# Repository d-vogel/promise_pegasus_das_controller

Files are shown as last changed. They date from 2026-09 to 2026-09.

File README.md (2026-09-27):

# Promise Pegasus DAS controller

The Promise Pegasus DAS is a thuderbolt 2 DAS enclosure.
| Front | Back |
|:-:|:-:|
|front|back|

The goal here is to reverse engineer the backplane and replace the RAID controller with a SATA breakout board and microcontroller.

# Current Status
## reverse engineering
The reverse engineering of the backplane is done, for now described in [docs/backplane.md](docs/backplane.md).

## v0
The first PCB version is not present on the repo. The pinout for both the PCI connector and the ATX24 connector was completely wrong.
Is seems in the debugging process I damaged the CPLD controlling the LEDs, which is why v2 will add a ws2812 control pin.

## v1
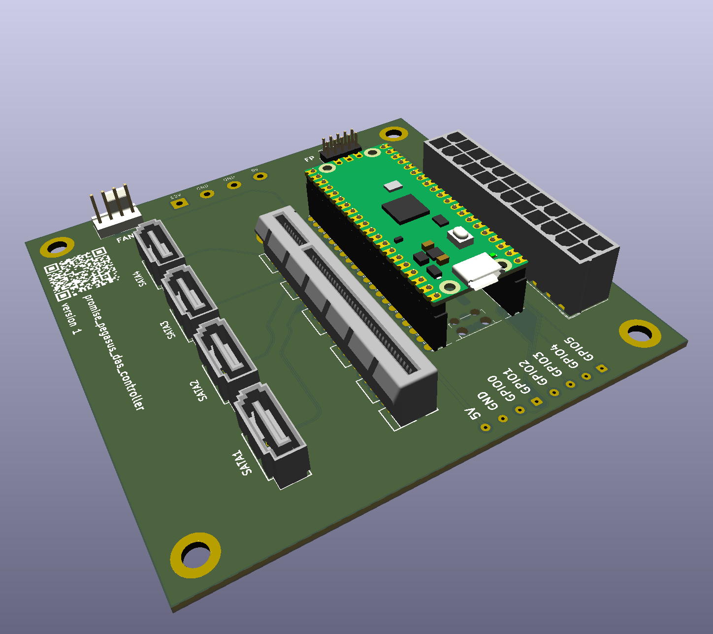
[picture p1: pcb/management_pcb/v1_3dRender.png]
v1


This is the current version on the PCB. Pinouts are correct: 
- ✅ the pico is always on
- ✅ the front panel interfaces to the pico
- ✅ pico triggers the PSU
- ✅ CPLD control pins arrive where they should
- ✅ Disk power enable pins work
- ✅ sata works (tested with HDD1 only)
- ❌ ground fill missing, bodge wires were needed.

## v2 (TODO)
- add ws2812 control pin to pico
- add ground fill to the PCB
- add onboard temperature sensor

## v3 eInk front panel?
[waveshare 2.9 inch E-paper Module](https://www.waveshare.com/2.9inch-e-paper-module.htm)

# BOM:
- SATA: https://www.mouser.ch/ProductDetail/Adam-Tech/SATA-A-PL-VT-K-1
- PCI: https://www.mouser.ch/ProductDetail/Amphenol-FCI/10018783-10212TLF
- ATX24pin: https://www.mouser.fr/ProductDetail/TE-Connectivity/1-1775099-3?qs=28ld6GkVMjRzvehyCXdQkg%3D%3D

pio simulator: https://ice458.github.io/tools/pio_sim/index.html

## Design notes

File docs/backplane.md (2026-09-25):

# Backplate
## Hardware

The backplane is connected to the controller by it's edge into a PCIe x8 connector.

| [Front](backplane_pinout-front.png) | [Back](backplane_pinout-back.png) |
|-|- |
| front | back |

Its' fonctionalities:
- route 12V and 5V to the disks
- pairs of disks can be powered on/off using `ENABLE_HDD12` and `ENABLE_HDD34` pins

- each disk has a blue activity led and a RGB (orange+blue+red) status led so that's 16 leds in total. These are controlled by the CPLD on the backplane. 
- The CPLD is controlled with a special seral protocol on `LED_CLK`, `LED_DATA`, `LED_LATCH_0` and `LED_LATCH_1` pins.
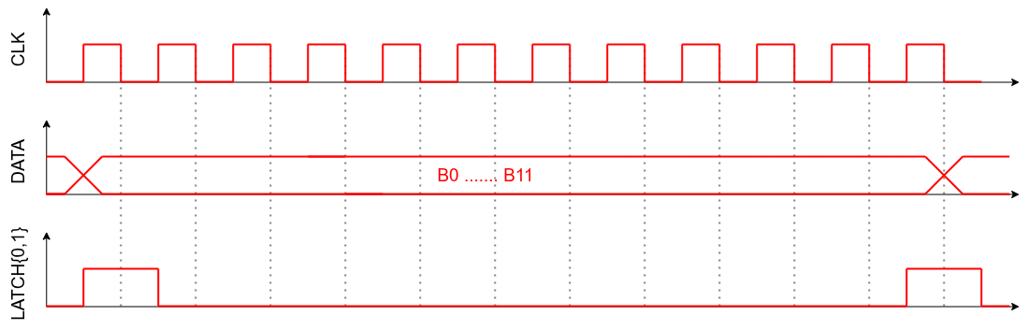
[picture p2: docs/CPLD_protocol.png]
led_protocol
- The procol is based on 12bit frames send over the DATA line at 62.5kHz. Latch signals are set high between each frame: 
- Bits are goupped by 3 for each of the 4 drive slots. The MSB of the group is the blue activity led, and the 2 LSBs are for the status led:
    |b2|b1|b0|result|
    |-|-|-|-|
    |0|x|x|activity off|
    |1|x|x|activity on|
    |x|0|0|status blue|
    |x|0|1|status red|
    |x|1|0|status orange|
    |x|1|1|status off|

- SATA pairs are directly routed to the connector.

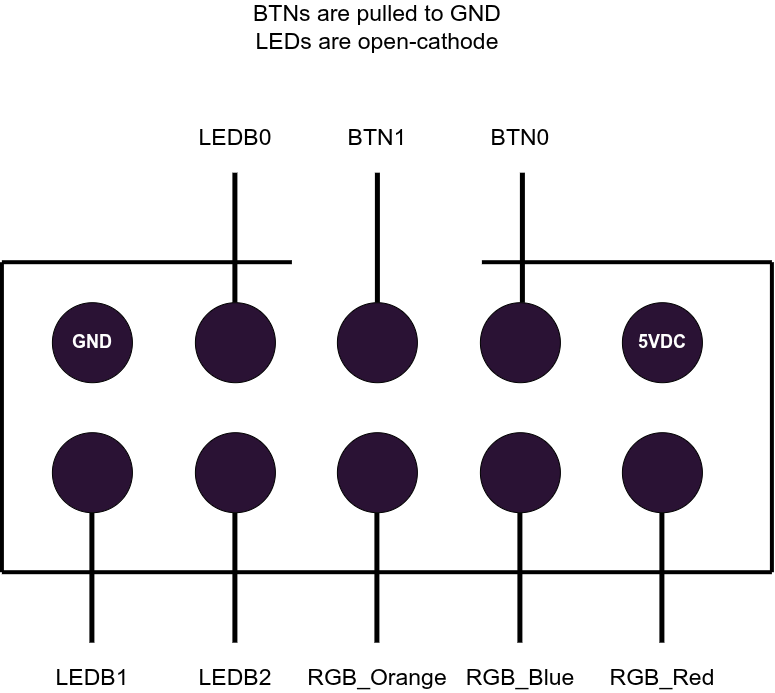
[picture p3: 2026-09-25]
docs/frontpanel_pinout.png

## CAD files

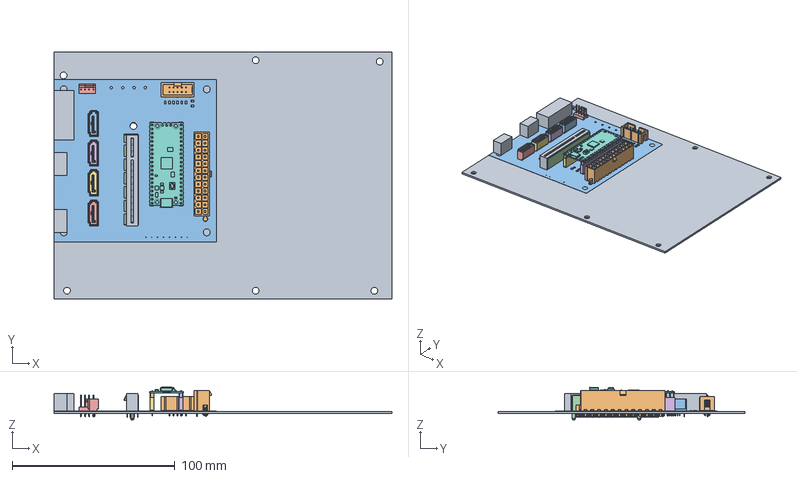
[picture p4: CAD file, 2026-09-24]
pcb/management_pcb/mecanical.FCStd
208.0 x 152.0 x 20.1 mm
original_board
R_0805_2012Metric
R_0805_2012Metric002
R_0805_2012Metric004
SATA-A-PL-VT-K-1
SATA-A-PL-VT-K-001
SATA-A-PL-VT-K-002
SATA-A-PL-VT-K-003
SATA-A-PL-VT-K-004
SATA-A-PL-VT-K-005
SATA-A-PL-VT-K-006
SATA-A-PL-VT-K-007
SATA-A-PL-VT-K-008
SATA-A-PL-VT-K-009
SATA-A-PL-VT-K-011
SATA-A-PL-VT-K-012
SATA-A-PL-VT-K-013
SATA-A-PL-VT-K-014
SATA-A-PL-VT-K-015
SATA-A-PL-VT-K-016
SATA-A-PL-VT-K-017
SATA-A-PL-VT-K-018
SATA-A-PL-VT-K-019
SATA-A-PL-VT-K-020
R_0805_2012Metric006
IDC_Header_2x05_P254mm_Vertical
SATA-A-PL-VT-K-022
SATA-A-PL-VT-K-023
SATA-A-PL-VT-K-024
SATA-A-PL-VT-K-025
SATA-A-PL-VT-K-026
SATA-A-PL-VT-K-027
SATA-A-PL-VT-K-028
SATA-A-PL-VT-K-029
SATA-A-PL-VT-K-030
SATA-A-PL-VT-K-031
R_0805_2012Metric008
SATA-A-PL-VT-K-033
SATA-A-PL-VT-K-034
SATA-A-PL-VT-K-035
SATA-A-PL-VT-K-036
SATA-A-PL-VT-K-037
SATA-A-PL-VT-K-038
SATA-A-PL-VT-K-039
SATA-A-PL-VT-K-040
SATA-A-PL-VT-K-041
SATA-A-PL-VT-K-042
R_0805_2012Metric010
R_0805_2012Metric012
C-1-1775099-3
R_0805_2012Metric014
DIP_98_310
Fan_Pin_Header_Straight_1x04
PinSocket_1x20_KiCad
PinSocket_1x20_KiCad001
RaspberryPi_Pico_Module_KiCad
RaspberryPi_Pico_Header_Breakaway_H2.54mm_KiCad
RaspberryPi_Pico_Header_Breakaway_H2.54mm_KiCad001
management_pcb_PCB

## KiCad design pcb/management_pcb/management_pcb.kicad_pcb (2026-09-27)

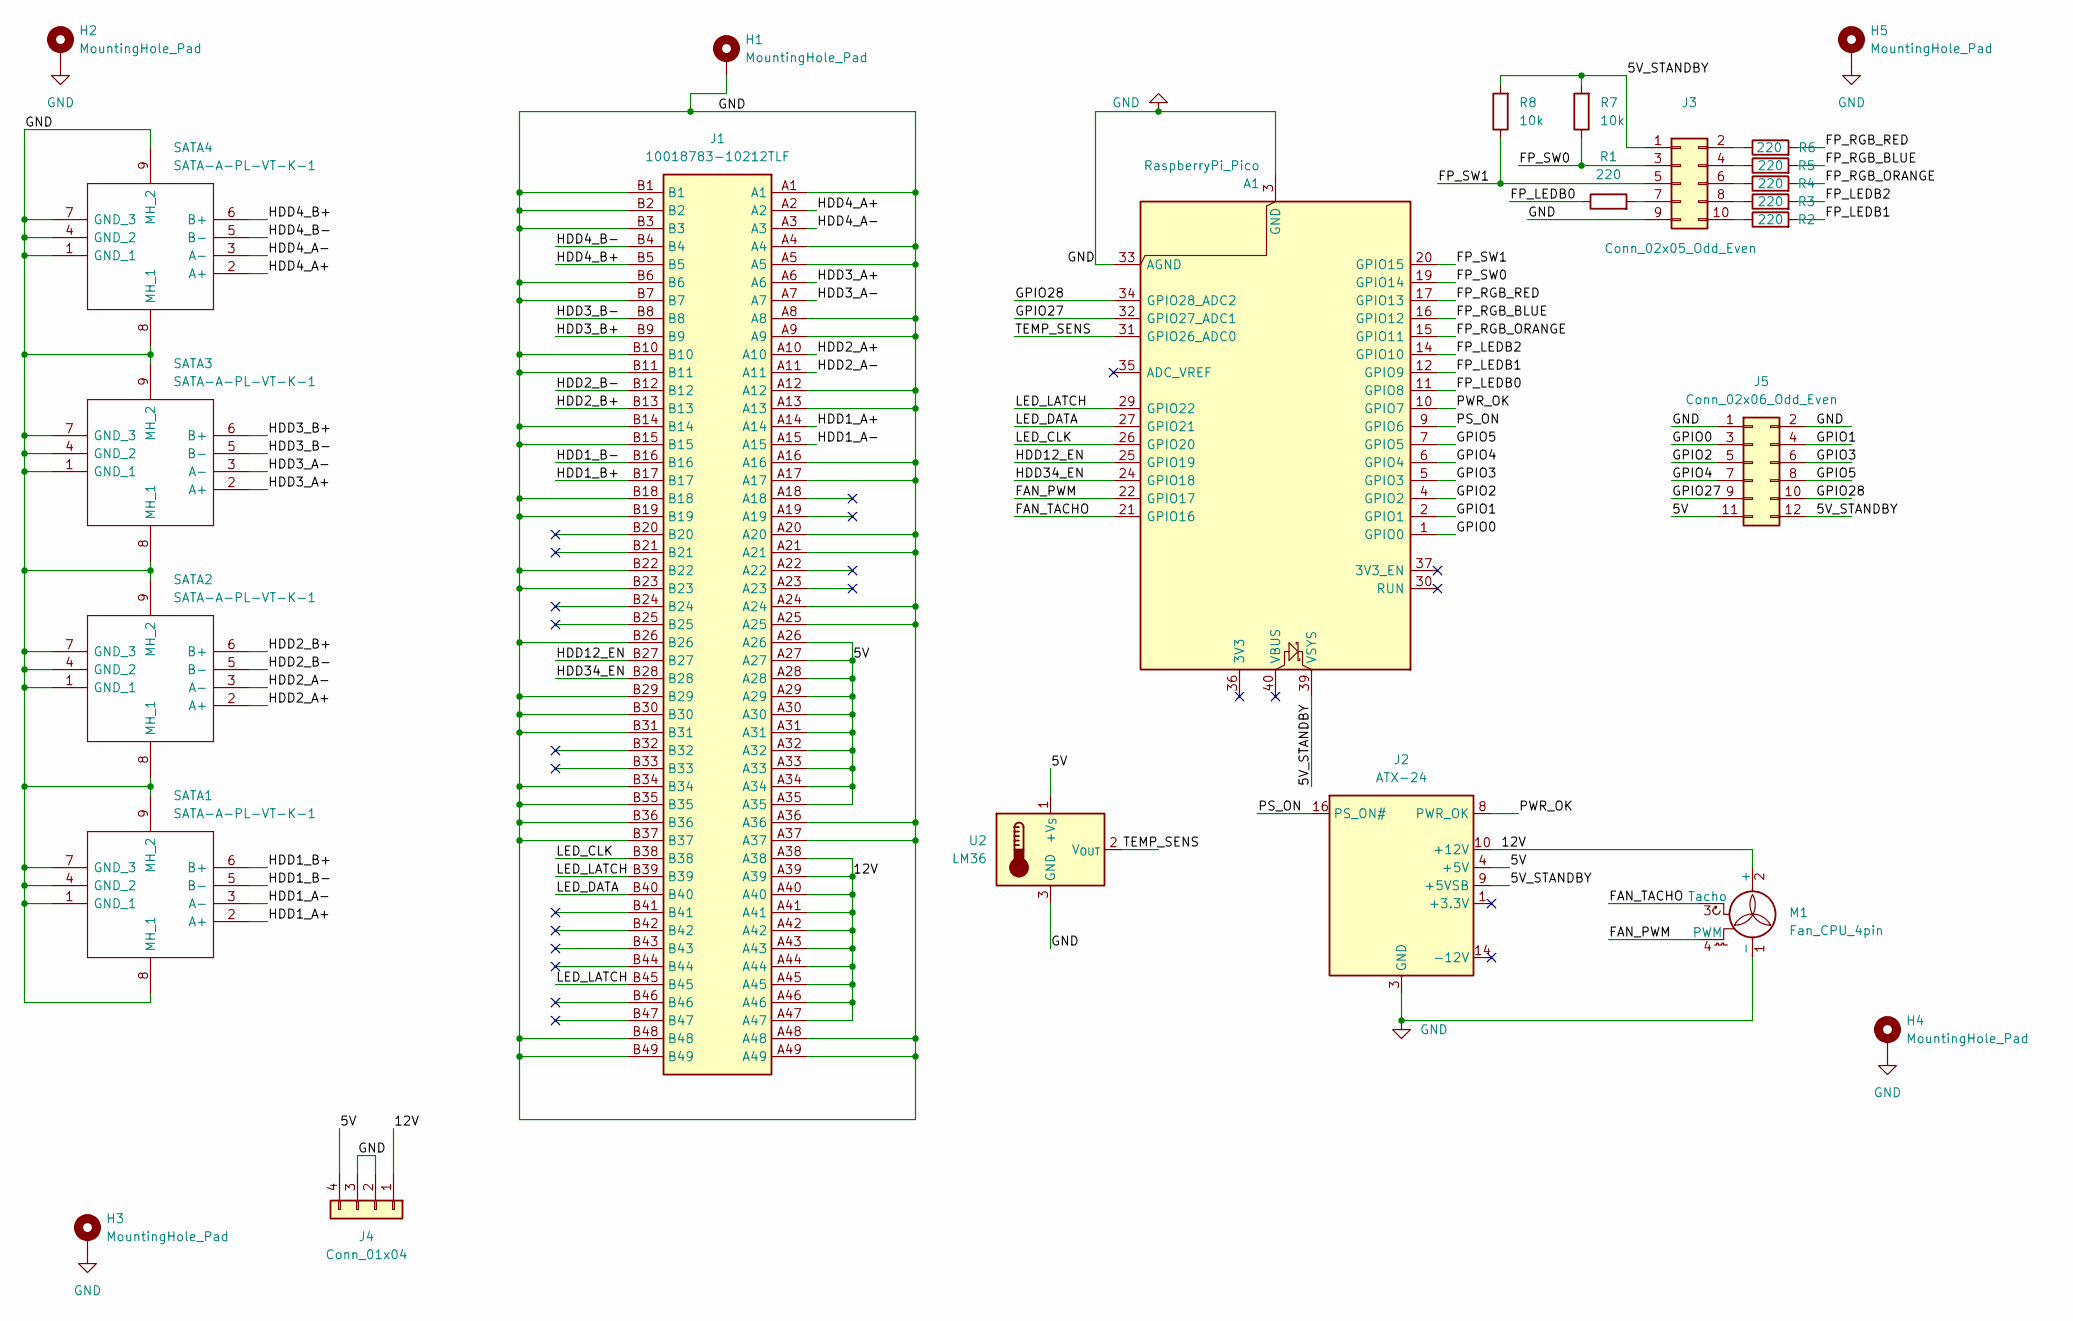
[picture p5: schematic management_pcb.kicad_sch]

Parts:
A1: RaspberryPi_Pico; RaspberryPi_Pico_Common_Unspecified
H1, H2, H3, H4, H5: MountingHole_Pad; MountingHole_4.3mm_M4_DIN965_Pad_TopBottom
J1: 10018783-10212TLF; 1001878310212TLF; Mouser Part Number 649-118783-10212TLF
J2: ATX-24; Molex_Mini-Fit_Jr_5566-24A_2x12_P4.20mm_Vertical
J3: Conn_02x05_Odd_Even; IDC_2x05_P2.00mm_Header
J4: Conn_01x04; SolderWire-0.75sqmm_1x04_P7mm_D1.25mm_OD3.5mm
J5: Conn_02x06_Odd_Even; PinHeader_2x06_P2.54mm_Vertical
M1: Fan_CPU_4pin; FanPinHeader_1x04_P2.54mm_Vertical
R1, R2, R3, R4, R5, R6: 220; R_0805_2012Metric
R7, R8: 10k; R_0805_2012Metric
SATA1, SATA2, SATA3, SATA4: SATA-A-PL-VT-K-1; SATAAPLVTK1; Manufacturer_Part_Number SATA-A-PL-VT-K-1
U2: LM36; TO-92_Inline

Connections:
/5V: J1.A26, J1.A27, J1.A28, J1.A29, J1.A30, J1.A31, J1.A32, J1.A33, J1.A34, J1.A35, J2.4 (+5V), J2.6 (+5V), J2.21 (+5V), J2.22 (+5V), J2.23 (+5V), J4.4, J5.11, U2.1 (+V_{S})
/5V_STANDBY: A1.39 (VSYS), J2.9 (+5VSB), J3.1, J5.12, R7.2, R8.2
/12V: J1.A38, J1.A39, J1.A40, J1.A41, J1.A42, J1.A43, J1.A44, J1.A45, J1.A46, J1.A47, J2.10 (+12V), J2.11 (+12V), J4.1, M1.2 (+)
/FAN_PWM: A1.22 (GPIO17), M1.4 (PWM)
/FAN_TACHO: A1.21 (GPIO16), M1.3 (Tacho)
/FP_LEDB0: A1.11 (GPIO8), R1.1
/FP_LEDB1: A1.12 (GPIO9), R2.2
/FP_LEDB2: A1.14 (GPIO10), R3.2
/FP_RGB_BLUE: A1.16 (GPIO12), R5.2
/FP_RGB_ORANGE: A1.15 (GPIO11), R4.2
/FP_RGB_RED: A1.17 (GPIO13), R6.2
/FP_SW0: A1.19 (GPIO14), J3.3, R7.1
/FP_SW1: A1.20 (GPIO15), J3.5, R8.1
/GPIO0: A1.1 (GPIO0), J5.3
/GPIO1: A1.2 (GPIO1), J5.4
/GPIO2: A1.4 (GPIO2), J5.5
/GPIO3: A1.5 (GPIO3), J5.6
/GPIO4: A1.6 (GPIO4), J5.7
/GPIO5: A1.7 (GPIO5), J5.8
/GPIO27: A1.32 (GPIO27_ADC1), J5.9
/GPIO28: A1.34 (GPIO28_ADC2), J5.10
/HDD1_A+: J1.A14, SATA1.2 (A+)
/HDD1_A-: J1.A15, SATA1.3 (A-)
/HDD1_B+: J1.B17, SATA1.6 (B+)
/HDD1_B-: J1.B16, SATA1.5 (B-)
/HDD2_A+: J1.A10, SATA2.2 (A+)
/HDD2_A-: J1.A11, SATA2.3 (A-)
/HDD2_B+: J1.B13, SATA2.6 (B+)
/HDD2_B-: J1.B12, SATA2.5 (B-)
/HDD3_A+: J1.A6, SATA3.2 (A+)
/HDD3_A-: J1.A7, SATA3.3 (A-)
/HDD3_B+: J1.B9, SATA3.6 (B+)
/HDD3_B-: J1.B8, SATA3.5 (B-)
/HDD4_A+: J1.A2, SATA4.2 (A+)
/HDD4_A-: J1.A3, SATA4.3 (A-)
/HDD4_B+: J1.B5, SATA4.6 (B+)
/HDD4_B-: J1.B4, SATA4.5 (B-)
/HDD12_EN: A1.25 (GPIO19), J1.B27
/HDD34_EN: A1.24 (GPIO18), J1.B28
/LED_CLK: A1.26 (GPIO20), J1.B38
/LED_DATA: A1.27 (GPIO21), J1.B40
/LED_LATCH: A1.29 (GPIO22), J1.B39, J1.B45
/PS_ON: A1.9 (GPIO6), J2.16 (PS_ON#)
/PWR_OK: A1.10 (GPIO7), J2.8 (PWR_OK)
/TEMP_SENS: A1.31 (GPIO26_ADC0), U2.2 (V_{OUT})
GND: A1.3 (GND), A1.8 (GND), A1.13 (GND), A1.18 (GND), A1.23 (GND), A1.28 (GND), A1.33 (AGND), A1.38 (GND), H1.1 (1_1), H2.1 (1_1), H3.1 (1_1), H4.1 (1_1), H5.1 (1_1), J1.A1, J1.A4, J1.A5, J1.A8, J1.A9, J1.A12, J1.A13, J1.A16, J1.A17, J1.A20, J1.A21, J1.A24, J1.A25, J1.A36, J1.A37, J1.A48, J1.A49, J1.B1, J1.B2, J1.B3, J1.B6, J1.B7, J1.B10, J1.B11, J1.B14, J1.B15, J1.B18, J1.B19, J1.B22, J1.B23, J1.B26, J1.B29, J1.B30, J1.B31, J1.B34, J1.B35, J1.B36, J1.B37, J1.B48, J1.B49, J2.3 (GND), J2.5 (GND), J2.7 (GND), J2.15 (GND), J2.17 (GND), J2.18 (GND), J2.19 (GND), J2.24 (GND), J3.9, J4.2, J4.3, J5.1, J5.2, M1.1 (-), SATA1.1 (GND_1), SATA1.4 (GND_2), SATA1.7 (GND_3), SATA1.8 (MH_1), SATA1.9 (MH_2), SATA2.1 (GND_1), SATA2.4 (GND_2), SATA2.7 (GND_3), SATA2.8 (MH_1), SATA2.9 (MH_2), SATA3.1 (GND_1), SATA3.4 (GND_2), SATA3.7 (GND_3), SATA3.8 (MH_1), SATA3.9 (MH_2), SATA4.1 (GND_1), SATA4.4 (GND_2), SATA4.7 (GND_3), SATA4.8 (MH_1), SATA4.9 (MH_2), U2.3 (GND)
unnamed: J3.2, R6.1
unnamed: J3.4, R5.1
unnamed: J3.6, R4.1
unnamed: J3.7, R1.2
unnamed: J3.8, R3.1
unnamed: J3.10, R2.1

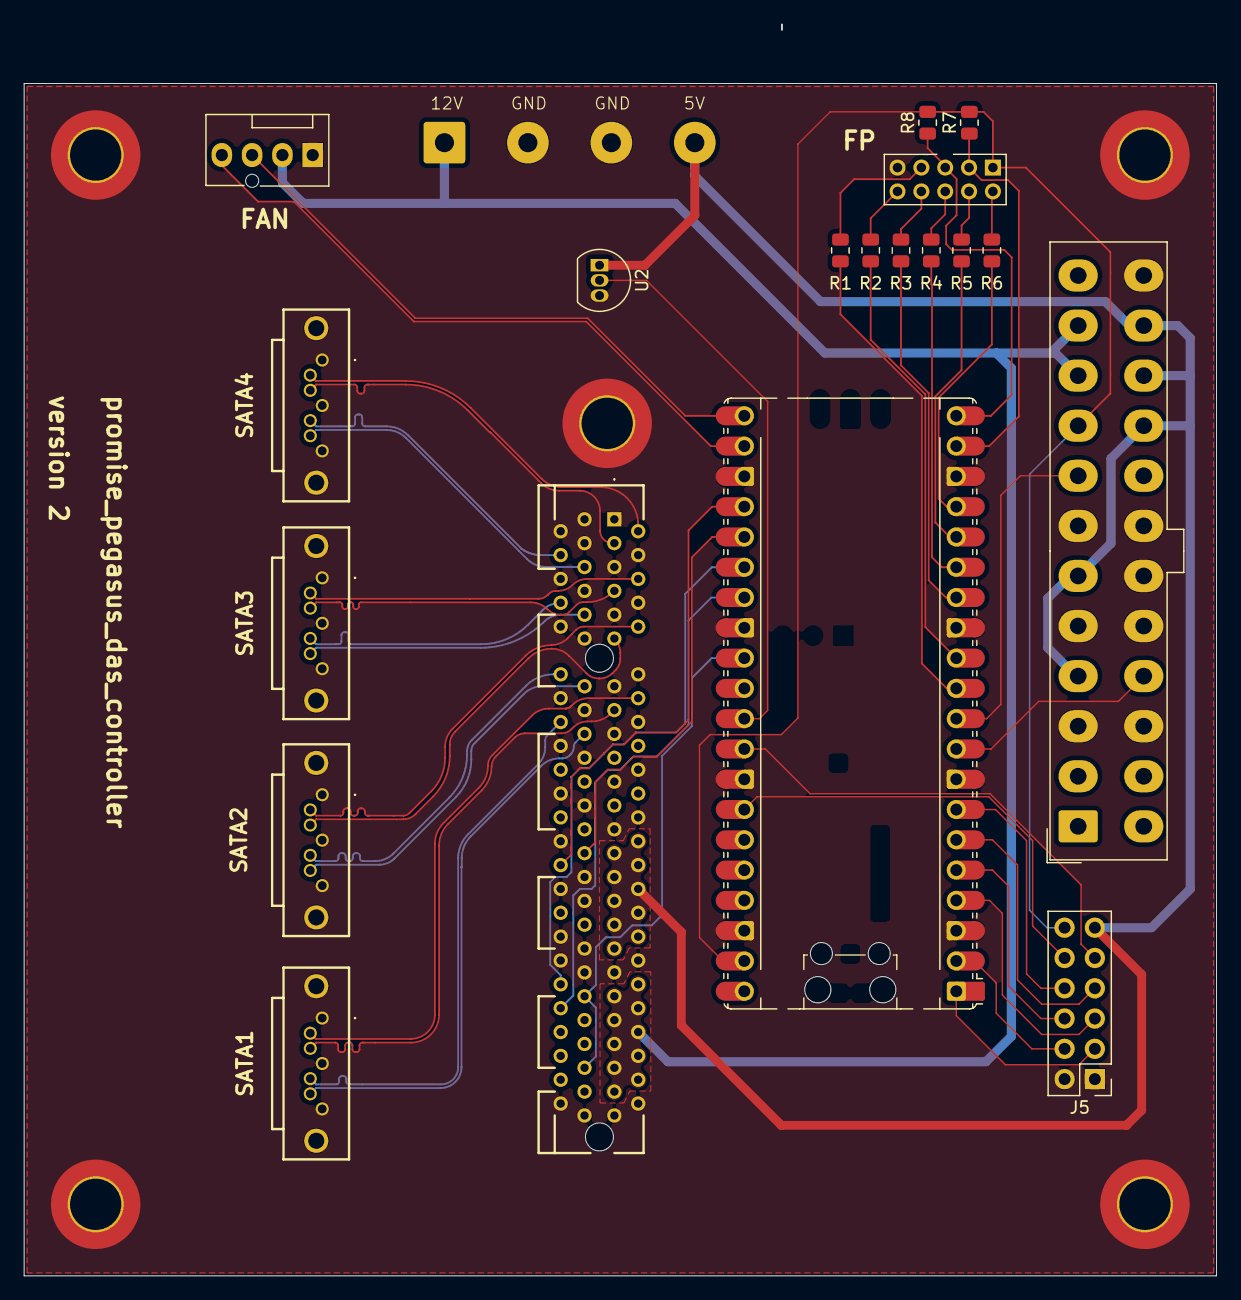
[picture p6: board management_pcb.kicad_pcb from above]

Board: 2 copper layers, 100.0 x 105.0 mm, 25 parts (0 on the bottom side), 52 nets.

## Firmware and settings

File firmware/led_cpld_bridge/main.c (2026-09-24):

#include <stdbool.h>
#include <stdio.h>
#include <stdlib.h>
#include <string.h>

#include "pico/stdlib.h"
#include "led_protocol.h"
#include "pico_pinout.h"

uint16_t press_count = 0;


static void print_help(void) {
    puts("Commands:");
    puts("  set <value>        set 12-bit frame (hex or decimal)");
    puts("  help               show this help text");
}

static uint16_t parse_value(const char *text) {
    if (text[0] == '0' && (text[1] == 'x' || text[1] == 'X')) {
        return (uint16_t)strtoul(text, NULL, 0);
    }
    return (uint16_t)strtoul(text, NULL, 10);
}

uint32_t btn_debounce_time = 0;
void gpio_callback(uint gpio, uint32_t events) {
    if (time_reached(btn_debounce_time)) {
        btn_debounce_time = time_us_32() + 200000;
        if(gpio==FP_SW0) press_count++;
        if(gpio==FP_SW1) press_count++;
    } else {
        return;
    }
    
}

int main(void) {
    stdio_init_all();
    sleep_ms(1500);
    gpio_init(PSU_ON);
    gpio_set_dir(PSU_ON, GPIO_OUT);
    gpio_put(PSU_ON, 0);
    
    gpio_init(HDD12_EN);
    gpio_set_dir(HDD12_EN, GPIO_OUT);
    gpio_put(HDD12_EN, 1);

    gpio_init(HDD34_EN);
    gpio_set_dir(HDD34_EN, GPIO_OUT);
    gpio_put(HDD34_EN, 1);

    gpio_init(PICO_LED);
    gpio_set_dir(PICO_LED, GPIO_OUT);
    gpio_put(PICO_LED, 0);

    gpio_init(FP_LEDB0);
    gpio_set_dir(FP_LEDB0, GPIO_OUT);
    gpio_put(FP_LEDB0, 1);
    gpio_init(FP_LEDB1);
    gpio_set_dir(FP_LEDB1, GPIO_OUT);
    gpio_put(FP_LEDB1, 1);
    gpio_init(FP_LEDB2);
    gpio_set_dir(FP_LEDB2, GPIO_OUT);
    gpio_put(FP_LEDB2, 1);
    gpio_init(FP_RGB_ORANGE);
    gpio_set_dir(FP_RGB_ORANGE, GPIO_OUT);
    gpio_put(FP_RGB_ORANGE, 1);
    gpio_init(FP_RGB_BLUE);
    gpio_set_dir(FP_RGB_BLUE, GPIO_OUT);
    gpio_put(FP_RGB_BLUE, 1);
    gpio_init(FP_RGB_RED);
    gpio_set_dir(FP_RGB_RED, GPIO_OUT);
    gpio_put(FP_RGB_RED, 1);
    gpio_init(FP_SW0);
    gpio_set_dir(FP_SW0, GPIO_IN);
    gpio_init(FP_SW1);
    gpio_set_dir(FP_SW1, GPIO_IN);

    gpio_set_irq_enabled_with_callback(FP_SW0, GPIO_IRQ_EDGE_FALL, true, &gpio_callback);
    gpio_set_irq_enabled(FP_SW1, GPIO_IRQ_EDGE_FALL, true);

    led_init();
    led_start();
    led_set_frame(0x0249);

    print_help();

    char line[64];
    size_t len = 0;
    uint16_t sweep_frame = 1;
    uint32_t pico_led_lastToggle = 0;

    while (true) {
        int ch = getchar_timeout_us(1000);
        if (ch != PICO_ERROR_TIMEOUT) {
            if (ch == '\r' || ch == '\n') {
                line[len] = '\0';
                len = 0;

                char cmd[16];
                char arg1[16];
                char arg2[16];
                if (sscanf(line, "%15s %15s %15s", cmd, arg1, arg2) >= 1) {
                    if (strcmp(cmd, "set") == 0 && sscanf(line, "%*s %15s", arg1) == 1) {
                        uint16_t value = parse_value(arg1) & 0x0FFF;
                        led_set_frame(value);
                        printf("frame set to 0x%03X\n", value);
                    } else if (strcmp(cmd, "help") == 0) {
                        print_help();
                    } else {
                        puts("unknown command");
                    }
                }
            } else if (len < sizeof(line) - 1) {
                line[len++] = (char)ch;
            }
        }

        switch (press_count) {
            case 1:
                gpio_put(FP_LEDB0, 0);
                break;
            case 2:
                gpio_put(FP_LEDB1, 0);
                break;
            case 3:
                gpio_put(FP_LEDB2, 0);
                break;
            case 4:
                gpio_put(FP_RGB_ORANGE, 0);
                gpio_put(FP_RGB_BLUE, 1);
                gpio_put(FP_RGB_RED, 1);
                break;
            case 5:
                gpio_put(FP_RGB_ORANGE, 1);
                gpio_put(FP_RGB_BLUE, 0);
                gpio_put(FP_RGB_RED, 1);
                break;
            case 6:
                gpio_put(FP_RGB_ORANGE, 1);
                gpio_put(FP_RGB_BLUE, 1);
                gpio_put(FP_RGB_RED, 0);
                break;
            case 7:
                gpio_put(FP_RGB_ORANGE, 0);
                gpio_put(FP_RGB_BLUE, 0);
                gpio_put(FP_RGB_RED, 1);
                break;
            case 8:
                gpio_put(FP_RGB_ORANGE, 1);
                gpio_put(FP_RGB_BLUE, 0);
                gpio_put(FP_RGB_RED, 0);
                break;
            case 9:
                gpio_put(FP_RGB_ORANGE, 0);
                gpio_put(FP_RGB_BLUE, 1);
                gpio_put(FP_RGB_RED, 0);
            case 10:
                gpio_put(FP_LEDB0, 1);
                gpio_put(FP_LEDB1, 1);
                gpio_put(FP_LEDB2, 1);
                gpio_put(FP_RGB_ORANGE, 1);
                gpio_put(FP_RGB_BLUE, 1);
                gpio_put(FP_RGB_RED, 1);
                press_count = 0;
                break;

            default:
                break;
        }
        
        if (time_reached(pico_led_lastToggle + 500000)) {
            pico_led_lastToggle = time_us_32();
            gpio_put(PICO_LED, !gpio_get(PICO_LED));
            // printf("Press count: %d\n", press_count);
        }
    }

    return 0;
}

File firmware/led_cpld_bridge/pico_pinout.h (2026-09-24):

#ifndef PICO_PINOUT_H
#define PICO_PINOUT_H

#define GPIO0 0
#define GPIO1 1
#define GPIO2 2
#define GPIO3 3
#define GPIO4 4
#define GPIO5 5
#define PSU_ON 6
#define PSU_PWR_OK 7
#define FP_LEDB0 8
#define FP_LEDB1 9
#define FP_LEDB2 10
#define FP_RGB_ORANGE 11
#define FP_RGB_BLUE 12
#define FP_RGB_RED 13
#define FP_SW0 14
#define FP_SW1 15
#define FAN_TACHO 16
#define FAN_PWM 17
#define HDD34_EN 18
#define HDD12_EN 19
#define LED_CLK 20
#define LED_DATA 21
#define LED_LATCH 22

#define PICO_LED 25

#endif // PICO_PINOUT_H

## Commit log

2026-09-24 Initial commit. The state is documented in the main Readme.
    [1-1775099-3.stp, 10018783-X0X12.stp, 2-1775099-0.stp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]
2026-09-25 Cleaded up component models, added 3d models.
    [1-1775099-3.stp, 2-1775099-0.stp, management_pcb.kicad_pcb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]
2026-09-25 added 3d render to readme
    [management_pcb.kicad_pcb]
2026-09-27 pcb v3 [untested]. Added TMP36 temperature sensor, more GPIO exposed.
    [management_pcb.kicad_pcb, management_pcb.kicad_sch]
